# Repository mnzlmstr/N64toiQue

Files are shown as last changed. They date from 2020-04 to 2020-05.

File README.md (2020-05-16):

### What is this Project about ?

In the early 2000s Nintendo released a version of the N64 Console for the Chinese Market called the iQue Player. This Console is much looked after and increasingly hard to come by.
This is made worse by the fact that the inputs, such as the Buttons and the Joystick are hardwired to the Console. As my console began to wear down I sought a way to be able to connect a standart N64 controller to the console. As this was not done yet I created this repository to aid people seeking to do something similar in collecting all the scarce information in one place

### How far along is the Project ?

The current code is working as intended and I played through the first Dungeons of Legen of Zelda - Ocarina of Time without any problems. However the Project is still a mess of wires, and not all Buttons have been hooked up yet. I intend to create a PCB to mount everything back into the origin casing and upload the Eagle Files to this repository, as well as to create assembly instructions and maybe also upload precompiled binaries.

While the first PRB Revision appears to be working right now i will look into improving the PCB to allow <br/>
the User to see if everything is in owrking Order by incorporating LEDs in the PCB as well as a header for 
Programming, which as of right now has to be done beforehand.

### What Hardware is needed for the Project ?

The code is designed to be run on a ESP32 Microprocessor from Espressif running @ 240Mhz.

### What Software is needed to compile from source ?

The code was compiled using Arduino IDE and version 1.0.4 of the Arduino-ESP32 Core.
As Timing is very critical (a bit read from the controller takes only 4uS !) I decided to not bother with working around the compiler optimizations and decided to disable them alltogether. This means you will have to edit the `platform.txt` file to set optimization level to -O0.

### Will I need to perform manual changes ?

Yes you will have to edit the Pins used in the file `PinMappings.h` to match the Pins you wired everything up with. The Axis pins have to be connected to the correct Wires coming from the Joystick. For that is adviced to cut the Joystick cable in half and connect the X-Axis pins to the pins labeled 1 & 4 of the Joystick PCB and the Y-Axis pins to the pins labeled 5 & 6.

### Changelog:

13.04.2020:<br/>
	- moved source code to `src` folder<br/>
	- added precompiled binaries for Heltec WiFi LoRa 32 V2 to folder `bin`<br/>
	- added first PCB Files (untested, just ordered them today) <br/>
<br/>
15.05.2020: <br/>
	- PCB has been tested an appears to be working just fine<br/>
	- Add: Updater to be able to upload new firmware over HTTP hosted by ESP32
	- Add: precompiled binary for firebeetle-esp32
	- TODO: redesigning PCB to incorporate LEDs for user feedback as well as Programming Header<br/>
<br/>

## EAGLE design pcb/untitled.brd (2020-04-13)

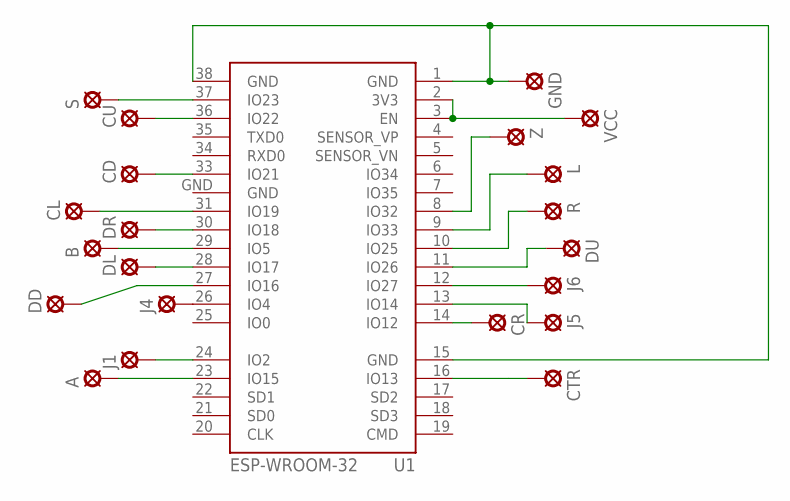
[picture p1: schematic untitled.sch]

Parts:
A: LSP13
B: LSP13
CD: LSP13
CL: LSP13
CR: LSP13
CTR: LSP13
CU: LSP13
DD: LSP13
DL: LSP13
DR: LSP13
DU: LSP13
GND: LSP13
J1, J4, J5, J6: LSP13
L: LSP13
R: LSP13
S: LSP13
U1: ESP-WROOM-32
VCC: LSP13
Z: LSP13

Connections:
GND: GND.MP, U1.1 (GND), U1.15 (GND), U1.38 (GND), U1.GND
unnamed: U1.8 (IO32), Z.MP
unnamed: U1.2 (3V3), U1.3 (EN), VCC.MP
unnamed: CTR.MP, U1.16 (IO13)
unnamed: A.MP, U1.23 (IO15)
unnamed: B.MP, U1.29 (IO5)
unnamed: S.MP, U1.37 (IO23)
unnamed: J4.MP, U1.26 (IO4)
unnamed: J1.MP, U1.24 (IO2)
unnamed: J6.MP, U1.12 (IO27)
unnamed: J5.MP, U1.13 (IO14)
unnamed: L.MP, U1.9 (IO33)
unnamed: R.MP, U1.10 (IO25)
unnamed: DU.MP, U1.11 (IO26)
unnamed: DD.MP, U1.27 (IO16)
unnamed: DL.MP, U1.28 (IO17)
unnamed: DR.MP, U1.30 (IO18)
unnamed: CU.MP, U1.36 (IO22)
unnamed: CD.MP, U1.33 (IO21)
unnamed: CL.MP, U1.31 (IO19)
unnamed: CR.MP, U1.14 (IO12)

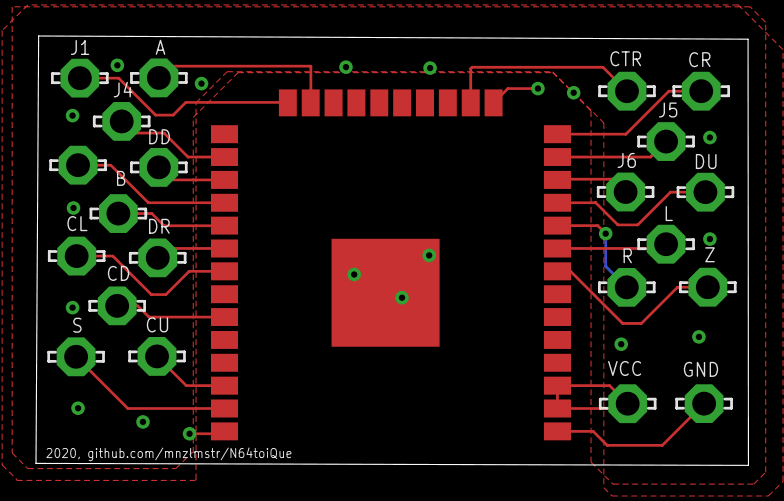
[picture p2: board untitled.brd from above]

Board: 2 copper layers, 39.6 x 23.9 mm, 22 parts (0 on the bottom side), 21 nets.

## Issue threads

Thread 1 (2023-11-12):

Where to solder to the iQue board

Progji, 2023-11-12:
I would like to know where I need to connect your PCB to the iQue board to do this project myself. Can you add some documentation?

Thanks in advance!

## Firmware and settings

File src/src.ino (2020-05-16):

#include "Output.h"
#include "ControllerData.h"
#include "ControllerBuffer.h"
#include "Debug.h"
#include "Updater.h"

ControllerData controller;

void setup()
{
  Serial.begin(115200);

  // setup io pins 
  setupIO();

  #ifdef PLOT_CONSOLE_POLLING
  delay(5000);
  sendCommand(0x01);
  while(true);
  #endif 

  sendCommand(0x01);
  updateOffsetsAndResolution();
}


void loop()
{
  // send command 0x01 to n64 controller 
  sendCommand(0x01);

  // store received data in controller struct 
  populateControllerStruct(&controller);

  // output received data to ique 
  outputToiQue(&controller);

  // polling must not occur faster than every 20 ms 
  delay(14);

  checkUpdateCombo(&controller);

  //Serial.printf("DPAD: %i %i %i %i \n",controller.DPadUp,controller.DPadDown,controller.DPadLeft,controller.DPadRight);
  //Serial.printf("C: %i %i %i %i \n",controller.CUp,controller.CDown,controller.CLeft,controller.CRight);

  //delay(5000);
}

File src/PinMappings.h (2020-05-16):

#ifndef PIN_MAPPINGS_H
#define PIN_MAPPINGS_H

#define DATA_PIN 13

#define PIN_BUTTON_A   15
#define PIN_BUTTON_B   5
#define PIN_BUTTON_Z   32
#define PIN_BUTTON_S   23
#define PIN_BUTTON_L   33
#define PIN_BUTTON_R   17

#define PIN_DPAD_UP    26
#define PIN_DPAD_DOWN  16
#define PIN_DPAD_LEFT  25
#define PIN_DPAD_RIGHT 18

#define PIN_C_UP       22
#define PIN_C_DOWN     21
#define PIN_C_LEFT     19
#define PIN_C_RIGHT    12

#define PIN_A_AXIS_X   14
#define PIN_B_AXIS_X   27

#define PIN_A_AXIS_Y   4
#define PIN_B_AXIS_Y   2

#define LINE_WRITE_HIGH pinMode(DATA_PIN,INPUT_PULLUP)
#define LINE_WRITE_LOW  pinMode(DATA_PIN,OUTPUT)


#endif 

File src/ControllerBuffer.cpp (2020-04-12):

#include "ControllerBuffer.h"
#include "PinMappings.h"
#include "Debug.h"

// buffer to hold data being read from controller 
bool buffer[DATA_SIZE + DATA_OFFSET];

// bit resolution and offsets
int bitOffsets[32];
int bitResolution;

/** Function to send a Command to the attached N64-Controller.
 *  Must be run from RAM to defy timing differences introduced from 
 *  reading Code from ESP32's SPI Flash Chip.
*/
void IRAM_ATTR sendCommand(byte command)
{
    // the current bit to write 
    bool bit;

    // clear output buffer 
    memset(buffer,0,DATA_SIZE + DATA_OFFSET);

    // for each bit
    for (int i = 0; i < 8; i++)
    {
        // get value
        bit = (1 << (7 - i)) & command;

        // write data
        LINE_WRITE_LOW;
        delayMicroseconds((3 - 2 * bit));
        LINE_WRITE_HIGH;
        delayMicroseconds((1 + 2 * bit));
    }

    // console stop bit
    LINE_WRITE_LOW;
    delayMicroseconds(1);
    LINE_WRITE_HIGH;
    delayMicroseconds(2);

    // read returned data as fast as possible 
    for(int i = 0;i < DATA_SIZE + DATA_OFFSET;i++)
    {
        buffer[i] = digitalRead(DATA_PIN);
    }

    // plot polling process from controller if unstructed to 
    #ifdef PLOT_CONSOLE_POLLING
    for(int i = 0; i < DATA_SIZE + DATA_OFFSET;i++)
    {
        Serial.println(buffer[i]*2500);
    }
    #endif
}

/* Function to extract a controller bit from the buffer of returned data */
void getBit(bool *bit,int offset,bool *data)
{
    // sanity check offset 
    if(offset < 0) offset = 0;

    // count 
    short count = 0;
  
    // get count from offset to offset + length
    for(int i = offset + DATA_OFFSET;i < offset + bitResolution;i++)
    {
        count += *(data + i);
    }

    // if offset surpasses threshold set bit 
    *bit = false;
    if(count > BIT_THRESHOLD) *bit = true;
}

/** Function to populate the controller struct if command 0x01 was sent.
 *  Buttons are set according to data in buffer, raw axis data is written,
 *  Axis Data is correctly decoded from raw axis data by taking two's complement
 *  and checking if value if below 'MAX_INCLINE_AXIS_X' or 'MAX_INCLINE_AXIS_Y'.
 *  If values surpass the maximum incline they are set to match those values.
 */
void populateControllerStruct(ControllerData *data)
{
    // first byte 
    getBit(&(data->buttonA) ,    bitOffsets[0]  ,&buffer[0]);
    getBit(&(data->buttonB),     bitOffsets[1]  ,&buffer[0]);
    getBit(&(data->buttonZ),     bitOffsets[2]  ,&buffer[0]);
    getBit(&(data->buttonStart), bitOffsets[3]  ,&buffer[0]);
    getBit(&(data->DPadUp),      bitOffsets[4] ,&buffer[0]);
    getBit(&(data->DPadDown),    bitOffsets[5] ,&buffer[0]);
    getBit(&(data->DPadLeft),    bitOffsets[6] ,&buffer[0]);
    getBit(&(data->DPadRight),   bitOffsets[7] ,&buffer[0]);

    // second byte, first two bits are unused 
    getBit(&(data->buttonL), bitOffsets[10]  ,&buffer[0]);
    getBit(&(data->buttonR), bitOffsets[11]  ,&buffer[0]);
    getBit(&(data->CUp),     bitOffsets[12] ,&buffer[0]);
    getBit(&(data->CDown),   bitOffsets[13] ,&buffer[0]);
    getBit(&(data->CLeft),   bitOffsets[14] ,&buffer[0]);
    getBit(&(data->CRight),  bitOffsets[15] ,&buffer[0]);

    // third byte 
    getBit(&(data->xAxisRaw[0]), bitOffsets[16], &buffer[0]);
    getBit(&(data->xAxisRaw[1]), bitOffsets[17], &buffer[0]);
    getBit(&(data->xAxisRaw[2]), bitOffsets[18], &buffer[0]);
    getBit(&(data->xAxisRaw[3]), bitOffsets[19], &buffer[0]);
    getBit(&(data->xAxisRaw[4]), bitOffsets[20], &buffer[0]);
    getBit(&(data->xAxisRaw[5]), bitOffsets[21], &buffer[0]);
    getBit(&(data->xAxisRaw[6]), bitOffsets[22], &buffer[0]);
    getBit(&(data->xAxisRaw[7]), bitOffsets[23], &buffer[0]);

    // fourth byte 
    getBit(&(data->yAxisRaw[0]), bitOffsets[24], &buffer[0]);
    getBit(&(data->yAxisRaw[1]), bitOffsets[25], &buffer[0]);
    getBit(&(data->yAxisRaw[2]), bitOffsets[26], &buffer[0]);
    getBit(&(data->yAxisRaw[3]), bitOffsets[27], &buffer[0]);
    getBit(&(data->yAxisRaw[4]), bitOffsets[28], &buffer[0]);
    getBit(&(data->yAxisRaw[5]), bitOffsets[29], &buffer[0]);
    getBit(&(data->yAxisRaw[6]), bitOffsets[30], &buffer[0]);
    getBit(&(data->yAxisRaw[7]), bitOffsets[31], &buffer[0]);

    // sum up bits to get axis bytes
    data->xAxis = 0;
    data->yAxis = 0; 
    for(int i = 0;i < 8;i++)
    {
        data->xAxis += (data->xAxisRaw[i] * (0x80 >> (i)));
        data->yAxis += (data->yAxisRaw[i] * (0x80 >> (i)));

        // print y axis values 
        #ifdef PRINT_Y_AXIS_VALUES
        Serial.printf("%i %i %i %i %i %i %i %i\n",data->yAxisRaw[0],data->yAxisRaw[1],data->yAxisRaw[2],data->yAxisRaw[3],data->yAxisRaw[4],data->yAxisRaw[5],data->yAxisRaw[6],data->yAxisRaw[7]);
        Serial.printf("yAxis: %i \n",data->yAxis);
        #endif

        // print x axis values 
        #ifdef PRINT_X_AXIS_VALUES
        Serial.printf("%i %i %i %i %i %i %i %i\n",data->xAxisRaw[0],data->xAxisRaw[1],data->xAxisRaw[2],data->xAxisRaw[3],data->xAxisRaw[4],data->xAxisRaw[5],data->xAxisRaw[6],data->xAxisRaw[7]);
        Serial.printf("xAxis: %i \n",data->xAxis);
        #endif
    }

    // decode xAxis two's complement 
    if(data->xAxis & 0x80)
    {
        data->xAxis = -1 * (0xff - data->xAxis);
    }

    // decode yAxis two's complement 
    if(data->yAxis & 0x80)
    {
        data->yAxis = -1 * (0xff - data->yAxis);
    }

    // keep x axis below maxIncline 
    if(data->xAxis >  MAX_INCLINE_AXIS_X) data->xAxis =  MAX_INCLINE_AXIS_X;
    if(data->xAxis < -MAX_INCLINE_AXIS_X) data->xAxis = -MAX_INCLINE_AXIS_X;

    // keep y axis below maxIncline
    if(data->yAxis >  MAX_INCLINE_AXIS_Y) data->yAxis =  MAX_INCLINE_AXIS_Y;
    if(data->yAxis < -MAX_INCLINE_AXIS_Y) data->yAxis = -MAX_INCLINE_AXIS_Y;

    //Serial.printf("xaxis: %-3i yaxis: %-3i \n",data->xAxis,data->yAxis);
}

void updateOffsetsAndResolution()
{
    // the current bit counter 
    int bitCounter = 0;

    // to hold the offset of A Button's falling edge 
    int bitAfallingOffset = 0;

    // iterate over buffer  
    for(int i = 0;i < DATA_SIZE + DATA_OFFSET - 1;i++)
    {
        // if a falling edge is detected 
        if(buffer[i] == true && buffer[1+i] == false)
        {
            // store bit's end offset 
            bitOffsets[bitCounter] = i+1;

            // if it's the A button store offset of the falling edge 
            if(bitCounter == 0) bitAfallingOffset = i+1;

            // if it's the B button calculate the bit Resolution 
            if(bitCounter == 1) bitResolution = (i+1) - bitAfallingOffset;

            // increment bit counter 
            bitCounter++;
        }
    }

    Serial.printf("Bit resolution is %i \n",bitResolution);

    // calculate bit's beginning offsets by subtracting resolution
    for(int i = 0;i < 32;i++)
    {
        bitOffsets[i] -= bitResolution;
        Serial.printf("beginning of bit %i detected @ begin+%i \n",i+1,bitOffsets[i]);
    }

    
}

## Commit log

2020-04-13 added PCB Layout
    [untitled.brd, untitled.sch]
2020-05-16 add: precompiled binary for firebeetle-esp32, add: HTTPUpdate functionality

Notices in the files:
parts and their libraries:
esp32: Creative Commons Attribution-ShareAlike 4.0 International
